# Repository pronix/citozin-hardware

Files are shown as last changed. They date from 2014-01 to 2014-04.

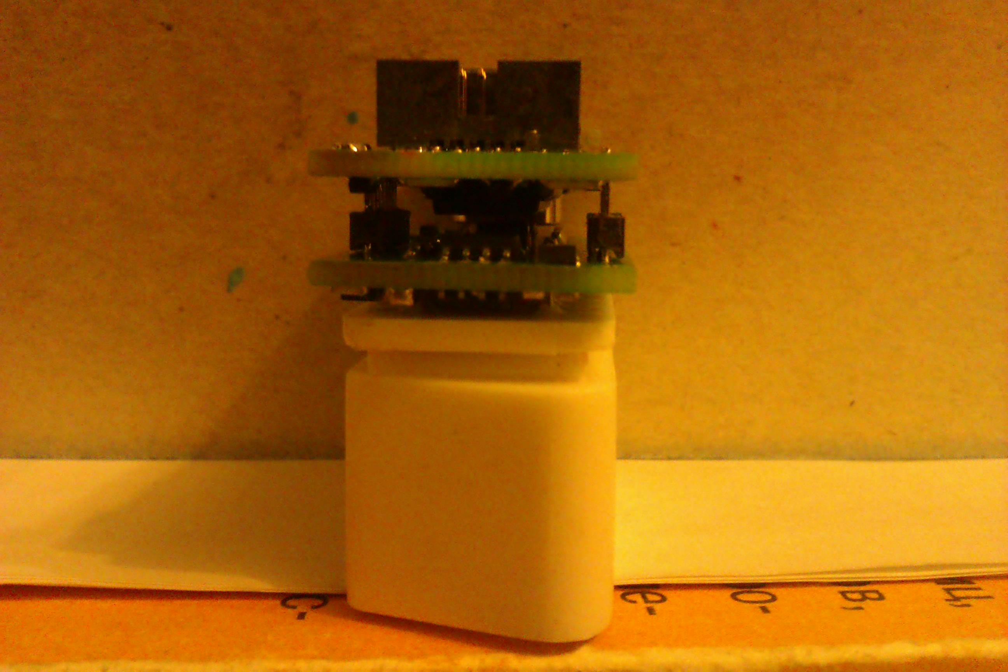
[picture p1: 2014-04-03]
OBDII-BLE112 v1.1.1/For Chinese/BOM+GERBER+ASSEMBLY/Assembly/view B.jpg

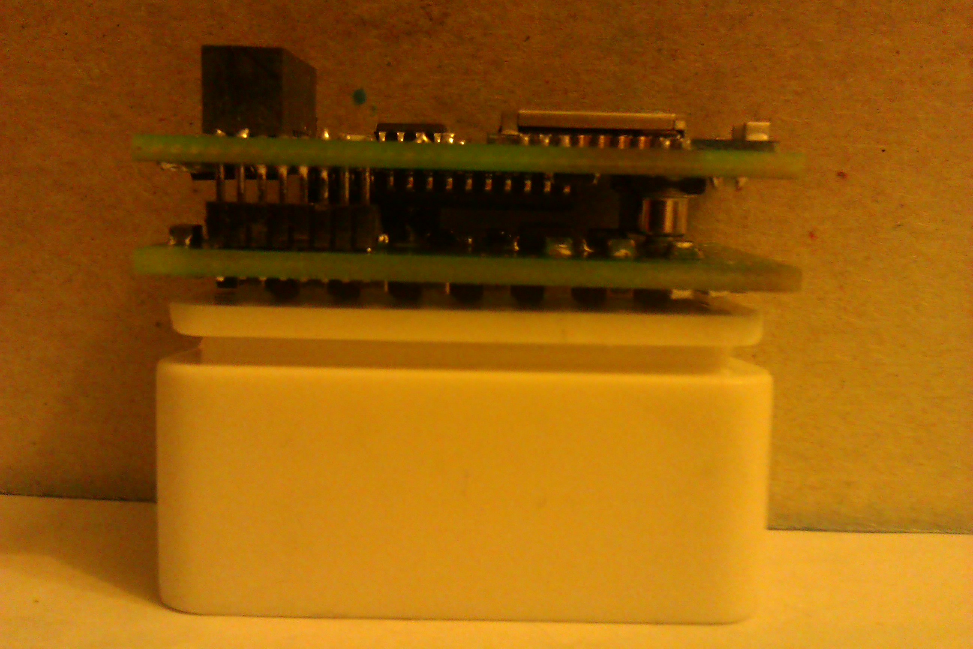
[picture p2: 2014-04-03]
OBDII-BLE112 v1.1.1/For Chinese/BOM+GERBER+ASSEMBLY/Assembly/view A.jpg

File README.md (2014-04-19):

v1.1.1
Citozin v1.1

Scantool for vachine on base of ELM327 v2.0  with BLE112-A to communicate with iPhone or Android supported Bluetooth LE (Bluetooth Smart).

	+Low Power mode
	+SAE J1850 PWM (41.6 kbaud)
	+SAE J1850 VPW (10.4 kbaud)
	+ISO 9141-2 (5 baud init, 10.4 kbaud)
	+ISO 14230-4 KWP (5 baud init, 10.4 kbaud)
	+ISO 14230-4 KWP (fast init, 10.4 kbaud)
	+ISO 15765-4 CAN (11 bit ID, 500 kbaud)
	+ISO 15765-4 CAN (29 bit ID, 500 kbaud)
	+ISO 15765-4 CAN (11 bit ID, 250 kbaud)
	+ISO 15765-4 CAN (29 bit ID, 250 kbaud)
	+SAE J1939
	
ELM327 and BLE112 communicate via UART (9600 baud, 8 data bit, no parity, 1 stop bit, no Flow Control).

	+Temperature of BLE112 can be obtain

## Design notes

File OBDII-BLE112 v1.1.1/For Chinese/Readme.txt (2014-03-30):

Boards bilateral.
Title: Citozin v1.1.1

Quantity: 3
Solder mask color: Blue
Color silkscreen: White 
PCB thickness: 1mm
Foil thickness: 18um
Automatic installation.

All files in the format 2.4 English (Inch).
OBDII-Ist.GM2 - outlines for scribing.
List of components for assembly is located in the  BOM.xls file.
Arrangement of components for assemble is located in the files: "Top Assembly.pdf", "Bottom Assembly.pdf", "3D-Bottom.png", "3D-Top.png".

PCB consist of two part.
Assembly scheme of PCB  is located in "Assembly scheme.png"

Body of quartz resonator must !!!not!!! touch the  pins of J1(DEV-09911 connector).

Assembly steps:
1. Divide  part A and part B of each other 
2. Solder all components except J2, J3.
3. Solder J2, J3 (M52-040023V2045)on part B.
4. Solder J1(DEV-09911) on part B.
5. Mount part A on J2, J3 and solder it.
6. Solder pad 2 and 3 of J7(Solder Jumper Switcher).
7. Don't solder J6(Solder Jumper).

----
Kind regards,
Mihail Konovalov
+79218815960

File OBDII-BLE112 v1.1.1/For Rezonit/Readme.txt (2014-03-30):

Платы двусторонние.
Название: Pronix-OBDII v1.1.1

Количество: 3шт.
С зеленой маской.
Толщина текстолита 1.5
Толщина фольги 18мкм.
Ручной монтаж.

Все файлы в формате 2.4 English (Inch).
OBDII-Ist.GM2 - контуры для скрайбирования.
Список SMD-компонентов для монтажа в файле BOM.xls
Расположение компонентов в файлах "Top Assembly.pdf", "Bottom Assembly.pdf", "Bottom 3D.png", "Top 3D.png"

----
С уважением, Коновалов Михаил Викторович. +79218815960

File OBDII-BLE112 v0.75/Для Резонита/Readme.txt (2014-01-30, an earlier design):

Срочный заказ!!

Платы двуcторонии.
Название: Pronix-OBD

Количество: 3шт.
С зеленой маской.
Толщина текстолита 1.5
Толщина фольги 18мкм.
Без шелкографии.

Все файлы в формате 2.4 English (Inch)
OBDII-Ist.GM1 - контуры для скрайбирования

----
С уважением, Коновалов Михаил Викторович. +79218815960

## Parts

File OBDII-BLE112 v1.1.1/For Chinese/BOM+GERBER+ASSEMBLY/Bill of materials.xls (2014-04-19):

Designator | Footprint | Quantity | Value | DesignItemId
C1, C2 | 1608[0603] | 2 | 0.1uF 16V | GRM188R61C104KA01D
C3, C4 | 1608[0603] | 2 | 27pF 50V | CC0603JRNPO9BN270
C6, C11 | C1005 | 2 | 1uF 50V | 298D105X0050P2T
C7, C12 | C0603 | 2 | 2.2uF 16V | 298D225X0016M2T
C8, C9 | 0402 | 2 | 560pF 50V | C0402C561J5GACTU
C10 | C1005 | 1 | 4.7uF 16V | 298D475X0016P2T
C13 | C0603 | 1 | 1uF 16V | 298D105X9016M2T
C14, C15, C16 | 1608[0603] | 3 | 1uF 16V | C1608X7R1C105K080AC
D1 | SMA,2.8mm | 1 |  | FM4001W-W
D2, D3 | SOD123 | 2 |  | MMSD4148T1G
J1 | DEV-09911 - II | 1 |  | OBDII_DEV-09911
J2, J3 | M52-040023V2045 | 2 |  | M52-040023V2045
J6 | Solder Jumper | 1 |  | Solder Jumper
J7 | Solder Jumper Switcher | 1 |  | Solder Jumper Switcher
L5 | LED-0805 | 1 |  | APT2012QBC/D
P1 | 20021521-00010T1LF | 1 |  | 20021521-00010T1LF
Q1, Q3, Q5, Q6, Q7 | SOT23 | 5 | 0.2A, 40V | MMBT3904LT1G
Q2, Q4 | SOT23 | 2 | 0.2A, -40V | MMBT3906LT1G
R1, R3, R10 | ERA-0805 | 3 | 22k 0.125 | ERA-6AEB223V
R2, R12, R20, R25 | ERA-0805 | 4 | 47k 0.125 | ERA-6AEB473V
R4, R6, R7, R14, R15, R24 | ERA-0805 | 6 | 4.7k 0.125 | ERA-6AEB472V
R8, R9, R11, R13, R26 | ERA-0805 | 5 | 10k 0.125 | ERA-6AEB103V
R16, R18 | ERA-0805 | 2 | 2.2k 0.125 | ERA-6AEB222V
R17, R19 | ERJ-1210 | 2 | 510R 0.5 | ERJ-14NF5100U
R21 | ERA-0805 | 1 | 33k 0.125 | ERA-6AEB333V
R22, R23 | ERA-0805 | 2 | 100R 0.125 | ERA-6AEB101V
R31 | ERA-0805 | 1 | 470R 0.125 | ERA-6AEB471V
U1 | SOIC-28N | 1 |  | ELM327_SOIC
U2 | SOIC8N | 1 |  | MCP2551-I/SN
U3 | SOIC8N | 1 |  | LP2954IM/NOPB
U4, U7 | SOIC8N | 2 |  | LP2951ACM-3.3/NOPB
U5 | BLE112-A - II | 1 |  | BLE112-A
U6 | TXB0102DCUR | 1 |  | TXB0102DCUR
X1 | HC-49/US | 1 | 4MHz | ABLS-4.000MHZ-B2-T

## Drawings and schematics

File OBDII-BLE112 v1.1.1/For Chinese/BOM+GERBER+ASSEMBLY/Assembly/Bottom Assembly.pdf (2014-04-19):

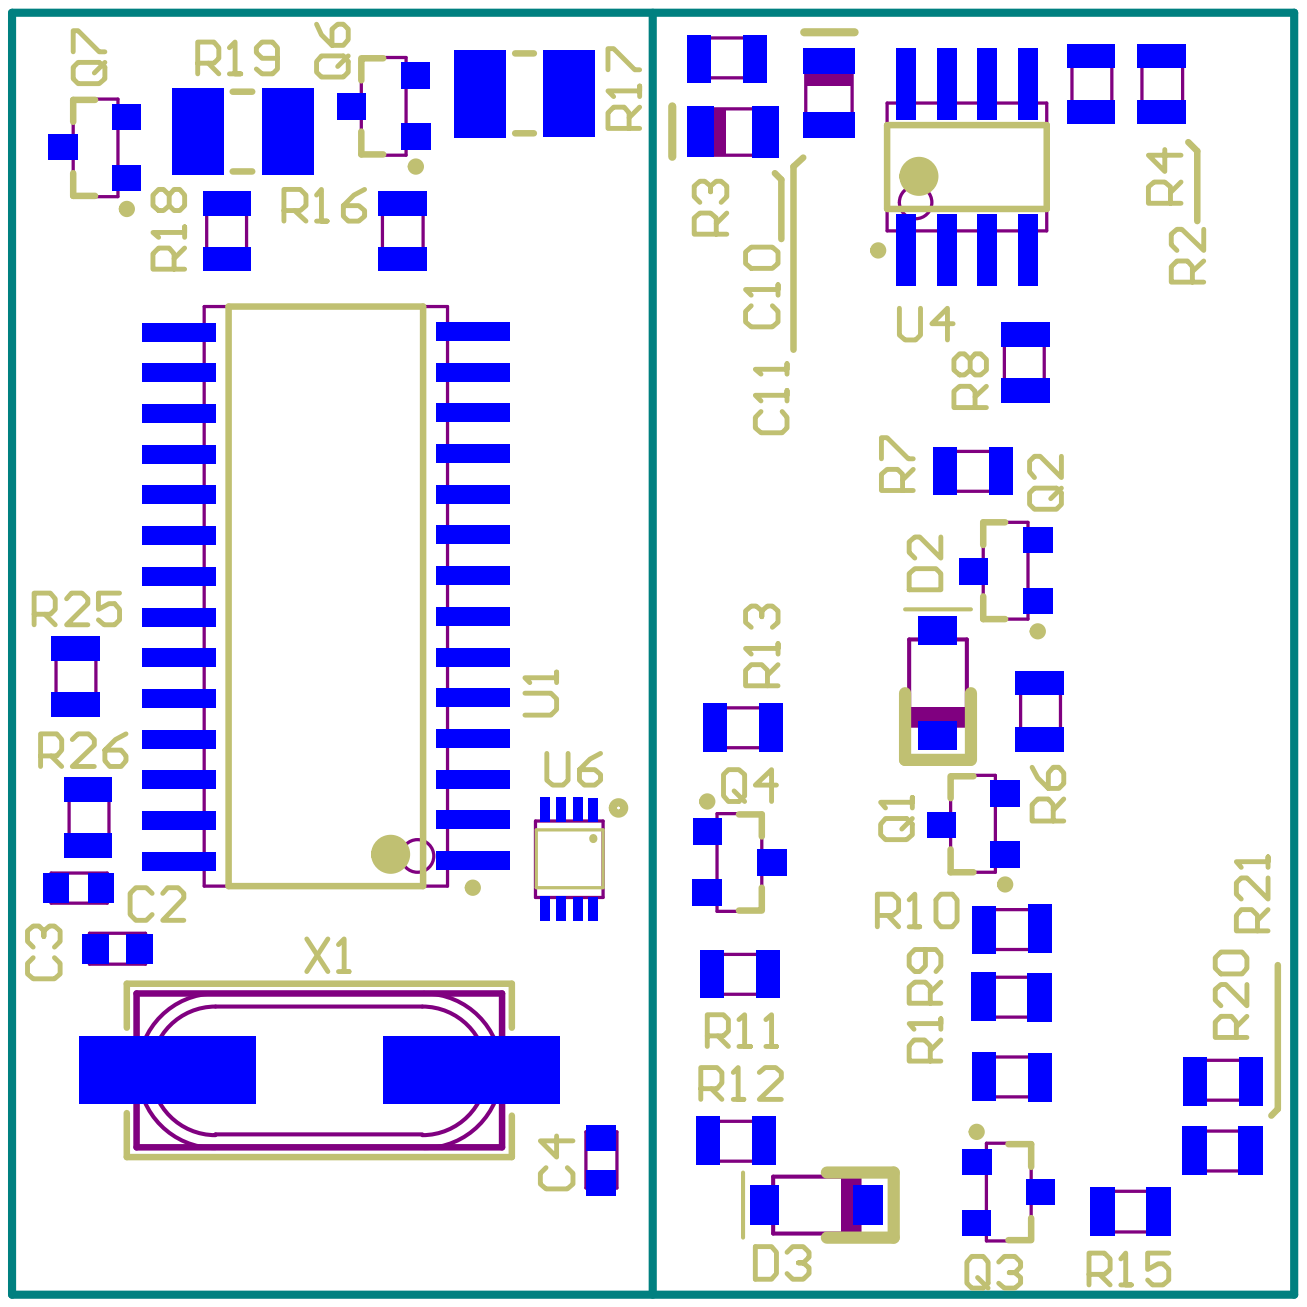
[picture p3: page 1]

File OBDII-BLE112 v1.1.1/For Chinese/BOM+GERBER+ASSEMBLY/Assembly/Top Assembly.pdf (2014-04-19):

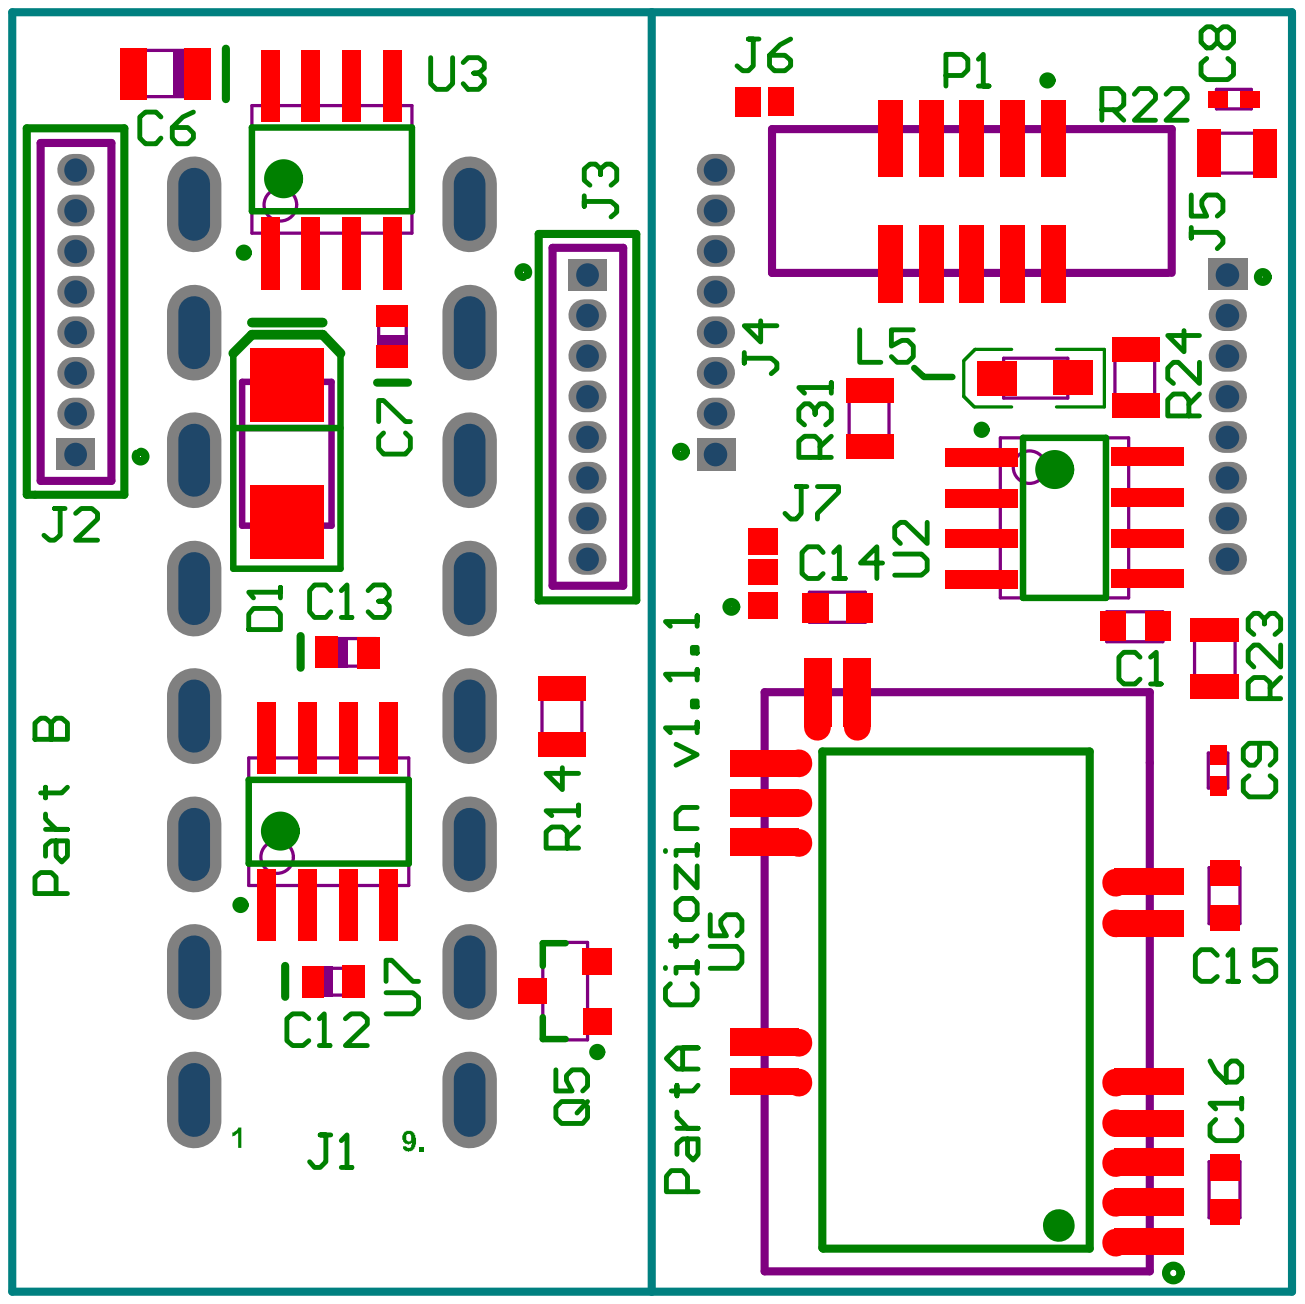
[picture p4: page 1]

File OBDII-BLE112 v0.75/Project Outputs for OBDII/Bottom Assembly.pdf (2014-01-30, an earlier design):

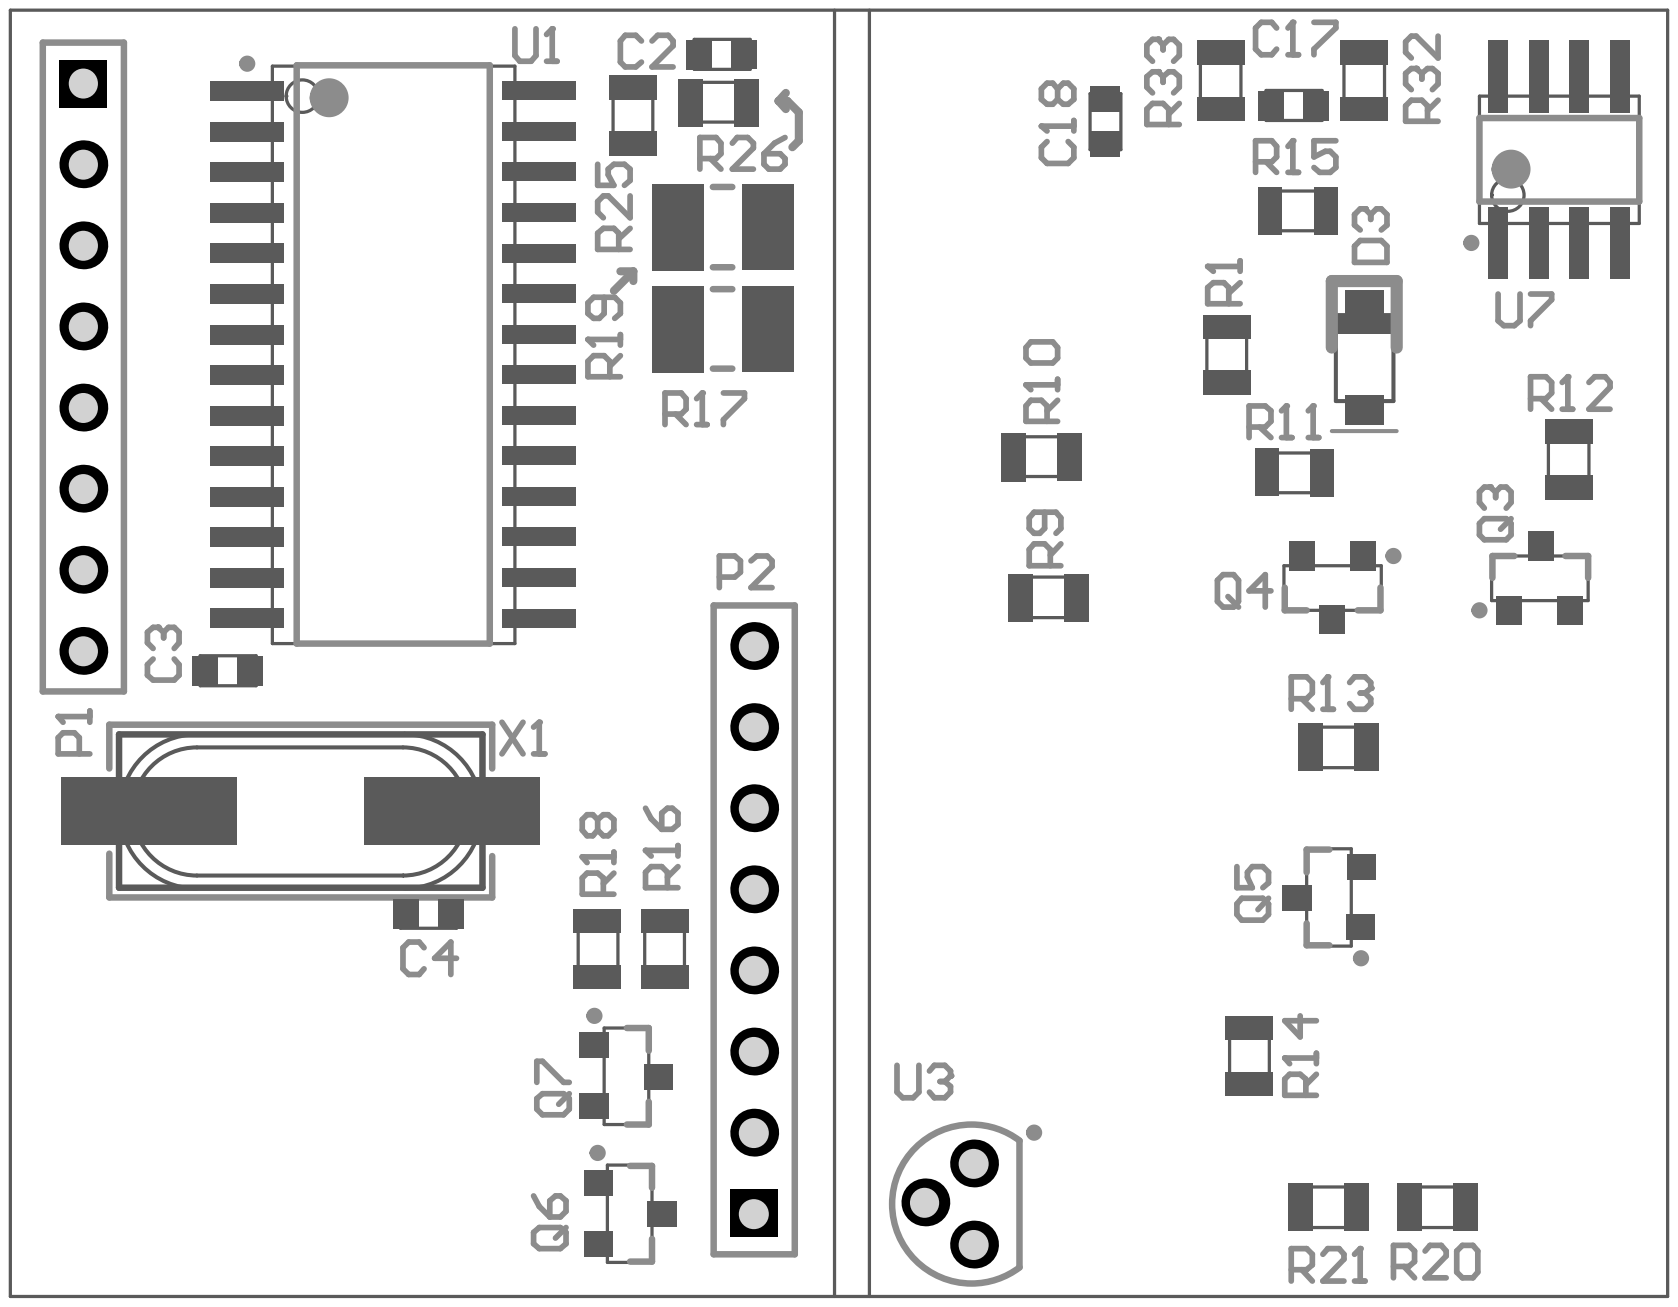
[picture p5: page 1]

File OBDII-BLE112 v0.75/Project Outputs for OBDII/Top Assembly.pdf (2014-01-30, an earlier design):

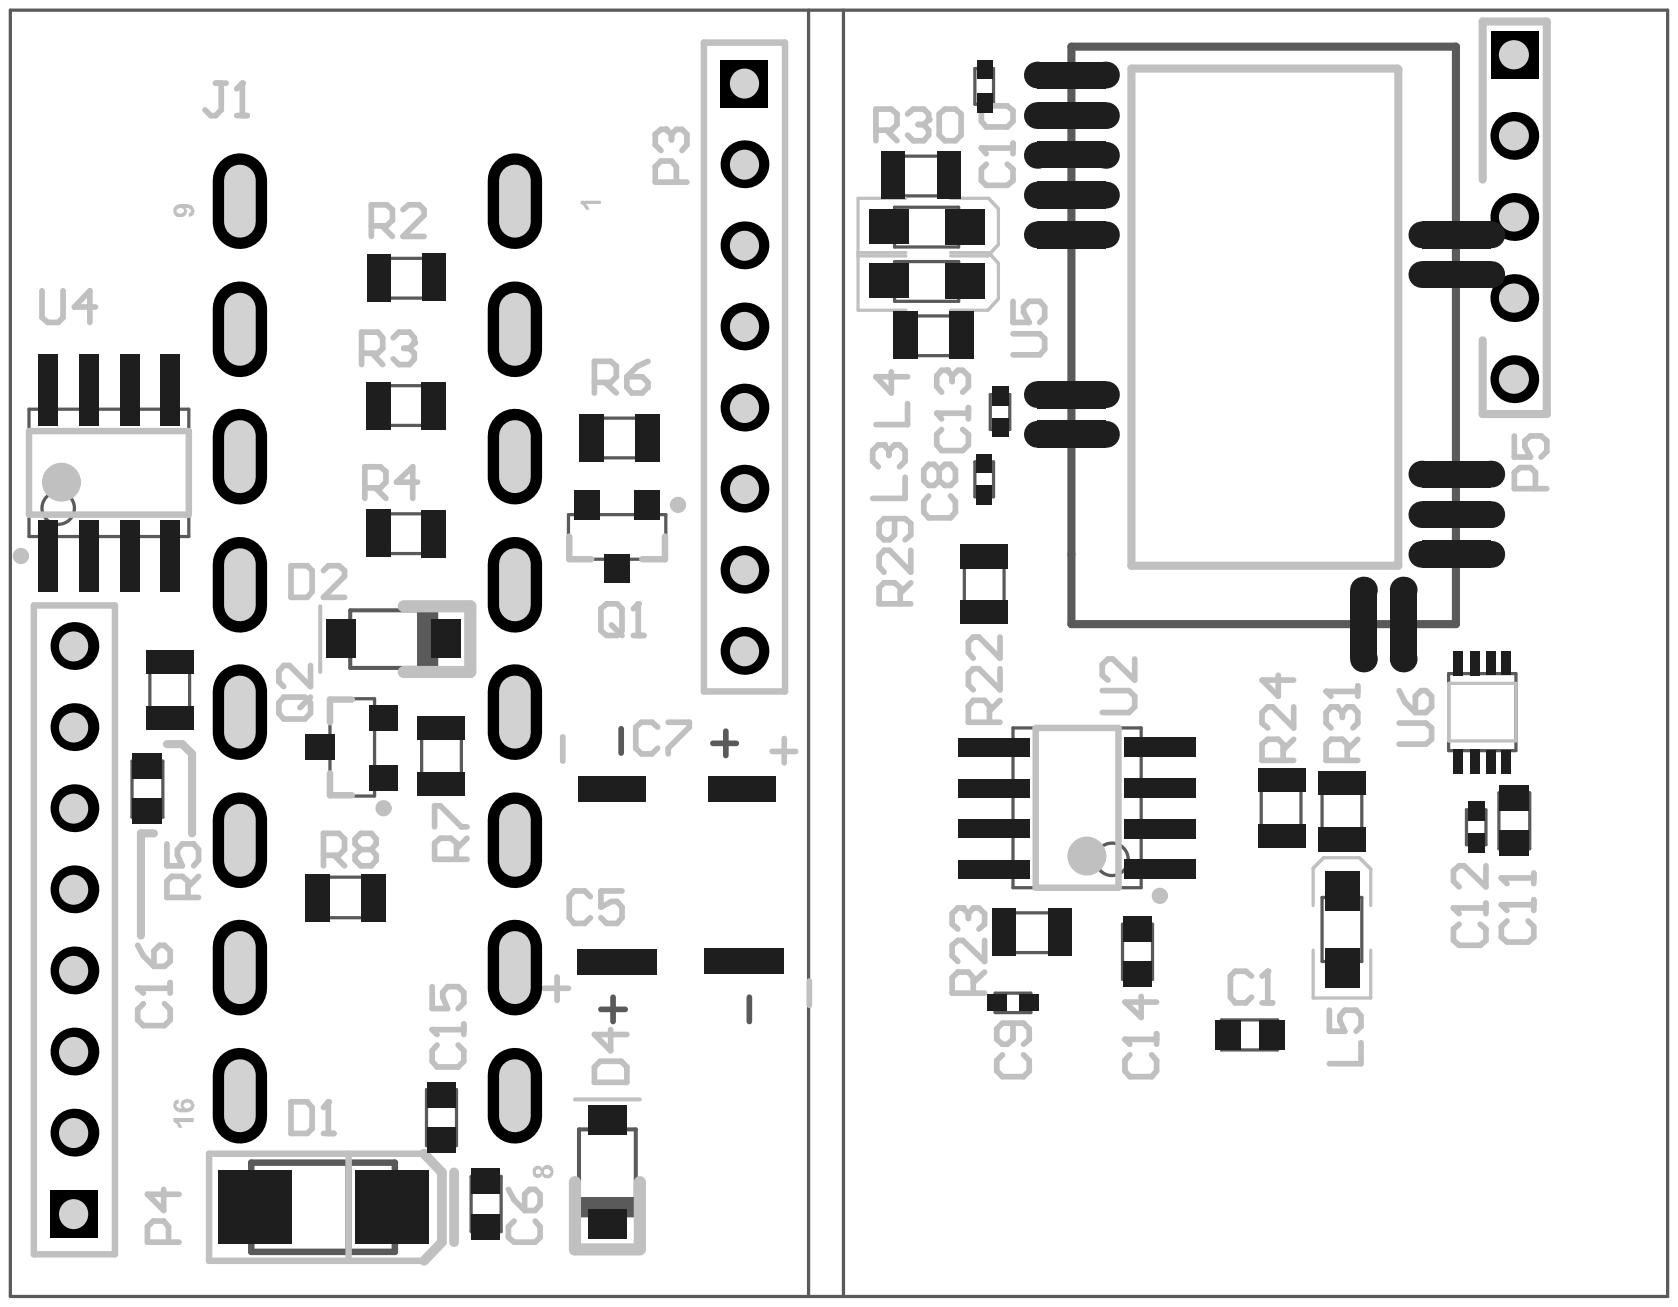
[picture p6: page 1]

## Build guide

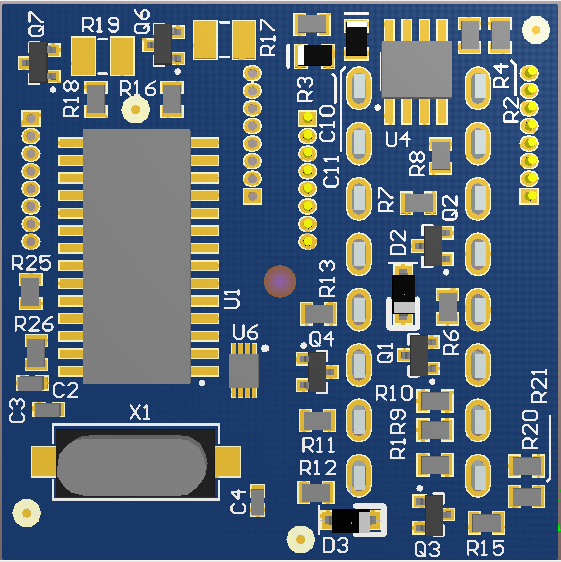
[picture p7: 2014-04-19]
OBDII-BLE112 v1.1.1/For Chinese/BOM+GERBER+ASSEMBLY/Assembly/3D-Bottom.png

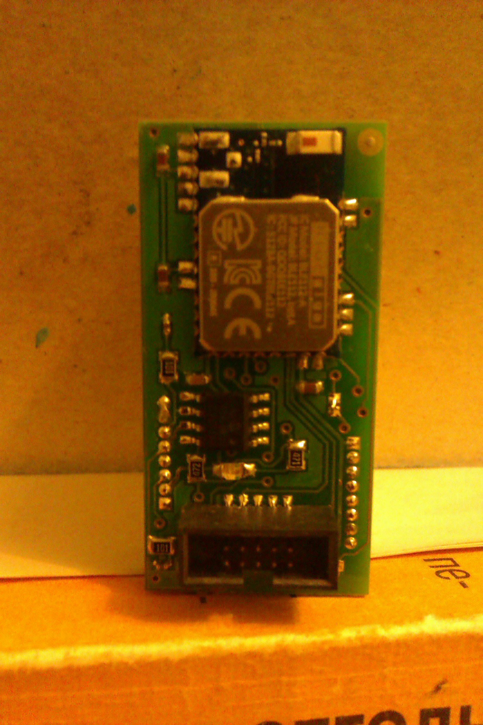
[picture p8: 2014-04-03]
OBDII-BLE112 v1.1.1/For Chinese/BOM+GERBER+ASSEMBLY/Assembly/veiw C.jpg

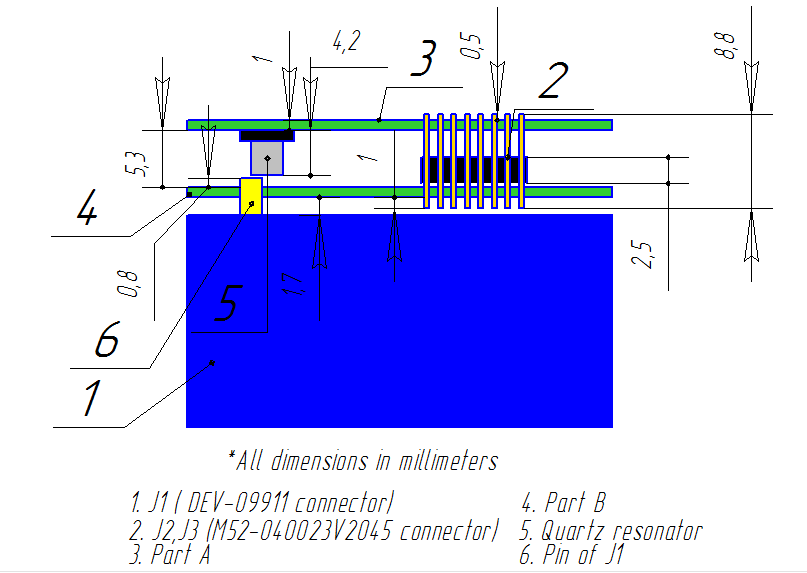
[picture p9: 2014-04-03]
OBDII-BLE112 v1.1.1/For Chinese/BOM+GERBER+ASSEMBLY/Assembly/Assembly scheme.png

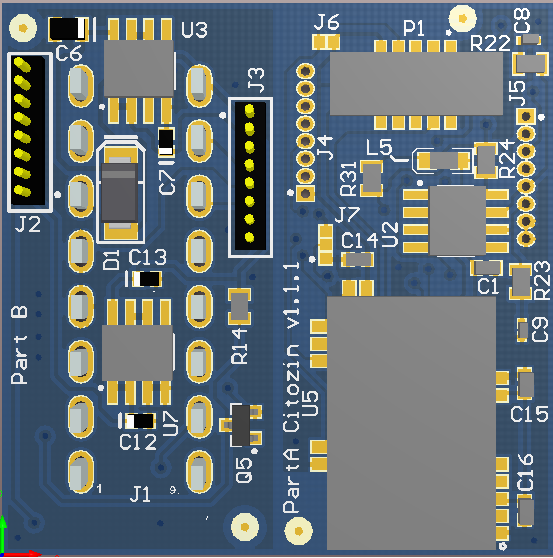
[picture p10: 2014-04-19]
OBDII-BLE112 v1.1.1/For Chinese/BOM+GERBER+ASSEMBLY/Assembly/3D-Top.png

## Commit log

2014-01-10 test text string
    [Power_.SchDoc]
2014-01-14 v.1.0.0 new PCB
    [OBDII.PrjPCB]
2014-01-29 Delete OBDII-Ist.PcbDoc
    error:out of date
    [OBDII-Ist.PcbDoc]
2014-03-30 v1.1.1 modification after test fabrication by rezonit
    [OBDII-Ist.GBL, OBDII-Ist.GBO, OBDII-Ist.GBP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]
2014-03-30 docs for Chine
    [Bill of materials.xls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]
2014-03-30 for chine
    [Bill of materials.xls]
2014-04-03 for china
    [OBDII-Ist.GBL, OBDII-Ist.GBO, OBDII-Ist.GBP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]
2014-04-19 v1.1.1 measurement of temperature added
